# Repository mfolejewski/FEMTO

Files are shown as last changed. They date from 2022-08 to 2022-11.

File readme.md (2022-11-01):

# Femto - RP2040 12x12mm PCB module

## Description

Femto is a ultra compact Raspberry Pi RP2040 module, which has features, as following:
- small footprint 12x12mm,
- all 30 GPIO pins connected,
- stamp form factor,
- 4-layer PCB board,
- onboard: QSPI Flash (USON8 package), 12MHz oscillator, PWR LED,
- fully open source project (OSHW).

Here you can find:
- \Photos: a few pictures of the assembled PCB boards
- \Python: simple script do test Femto module using Femto Tester board (use Thonny IDE)
- \manufacturing_files: all the production files for ordering PCB and assembly at JLCPCB (Gerber files, Pick & Place, BOM, etc.)
- \source_files: source files in Kicad and Altium Designer format

The main goal and reason to create this project was attempt to design as smallest as possible, and fully functional RP2040 module. Please note, that RP2040 MCU nas 7x7mm package, and Femto module has only a bit more, 12x12mm. In comparision, closer competitiors, such as Raspberry Pi Pico or RP2040 Stamp (Solder Party) have appropriately 51x21mm and 25x25mm.

The project consists of 3 parts:
- Module (mainboard)
- frame (solder frame)
- tester (testbench, only for functional verification)

## License

Project published as Open Source Hardware (OSHW) under CERN OHL v1.2 (Open Hardware Licence).



Project has been certified as Open Source Hardware by the Open Source Hardware Association (OSHWA).

UID is: PL000009

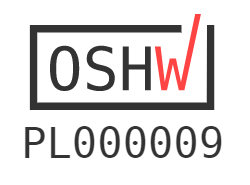
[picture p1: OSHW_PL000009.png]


https://certification.oshwa.org/pl000009.html

## Press release:

[hackster.io](http://hackster.io/news/mirek-folejewski-s-femto-module-is-a-full-feature-raspberry-pi-rp2040-in-the-smallest-footprint-yet-d75727c4adbf.amp)

[cnx-software.com](https://cnx-software.com/2022/08/22/femto-tiny-raspberry-pi-rp2040-module/)

[blingeach.com](https://blingeach.com/mirek-folejewskis-femto-module-is-a-full-function-raspberry-pi-rp2040-within-the-smallest-footprint-but/)

[tecnohub.org](https://tecnohub.org/2022/08/a-full-featured-raspberry-pi-rp2040-in.html?m=1)

[theperfectech.com](https://theperfectech.com/mirek-folejewskis-femto-module-is-a-full-characteristic-raspberry-pi-rp2040-within-the-smallest-footprint-but/)

[hackaday.io](https://hackaday.io/project/186871-femto-module-v1)

## Photos

Raspberry Pico and Femto Module v1:
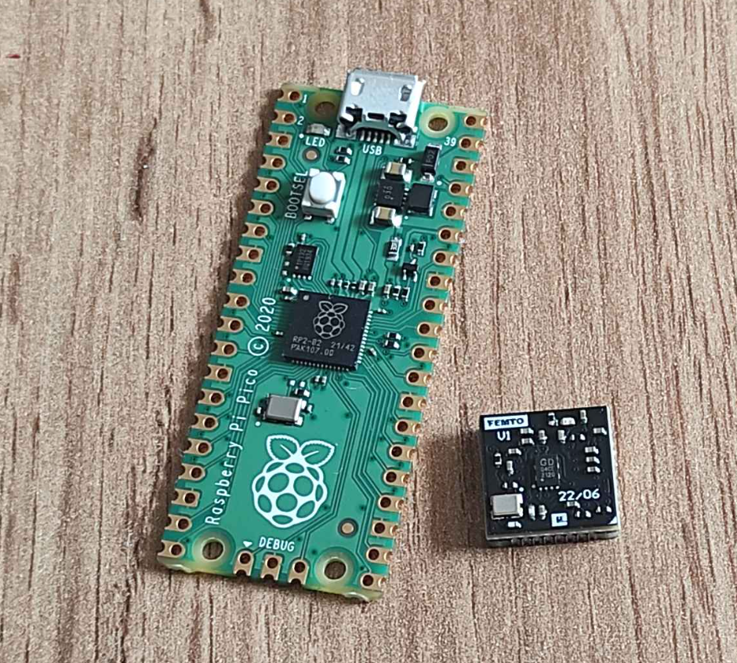
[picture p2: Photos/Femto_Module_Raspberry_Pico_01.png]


Femto Module:
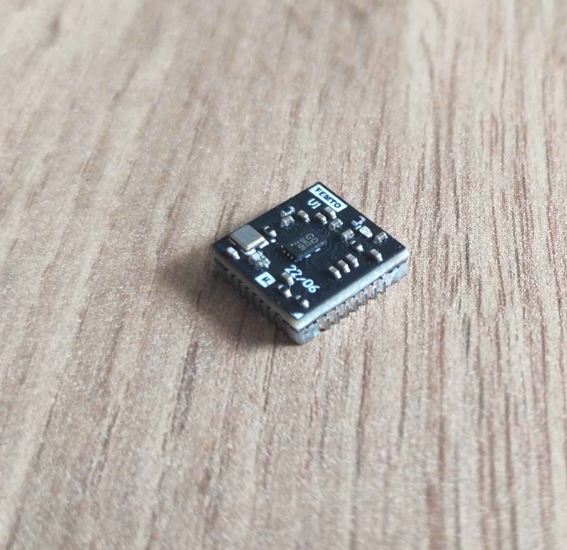
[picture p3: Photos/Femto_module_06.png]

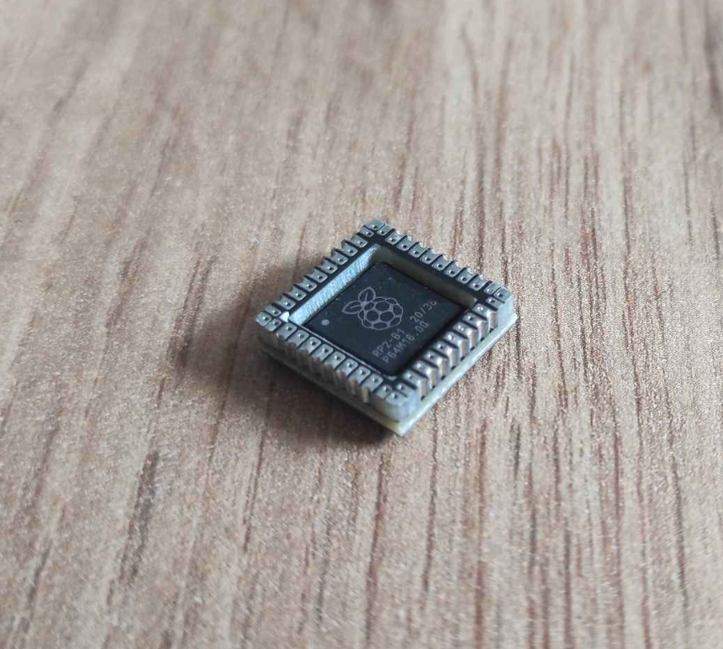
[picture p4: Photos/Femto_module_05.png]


Femto Frame:
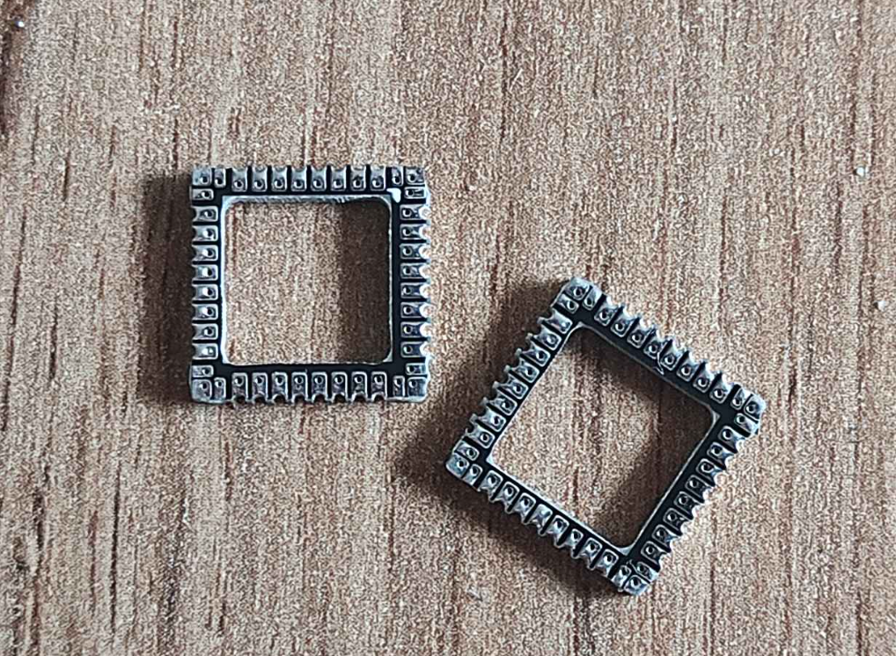
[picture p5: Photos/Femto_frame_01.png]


Femto Tester:
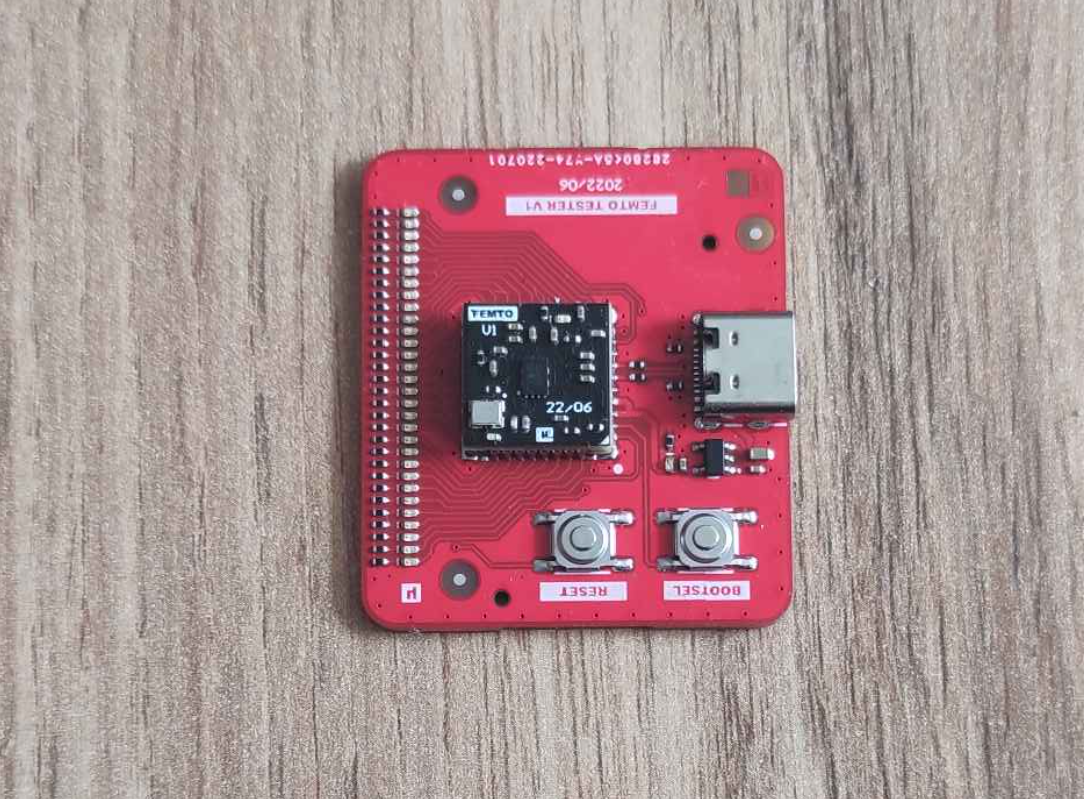
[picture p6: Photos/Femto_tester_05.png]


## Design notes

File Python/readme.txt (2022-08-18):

Python verification script for Femto Tester board

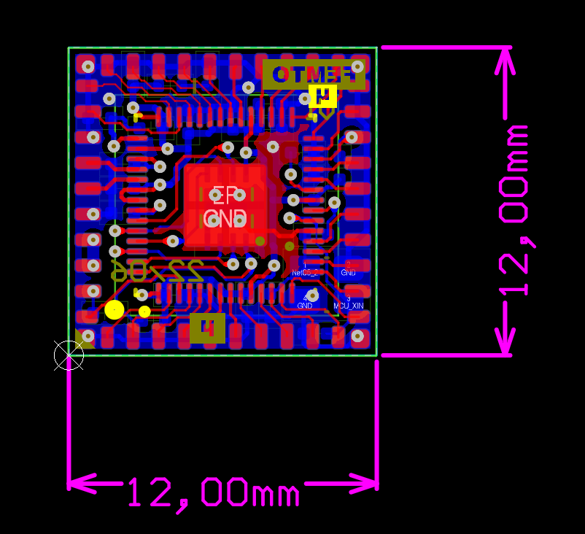
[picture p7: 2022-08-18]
source_files/Altium_Designer/Module/PCB_file_2d_view.png

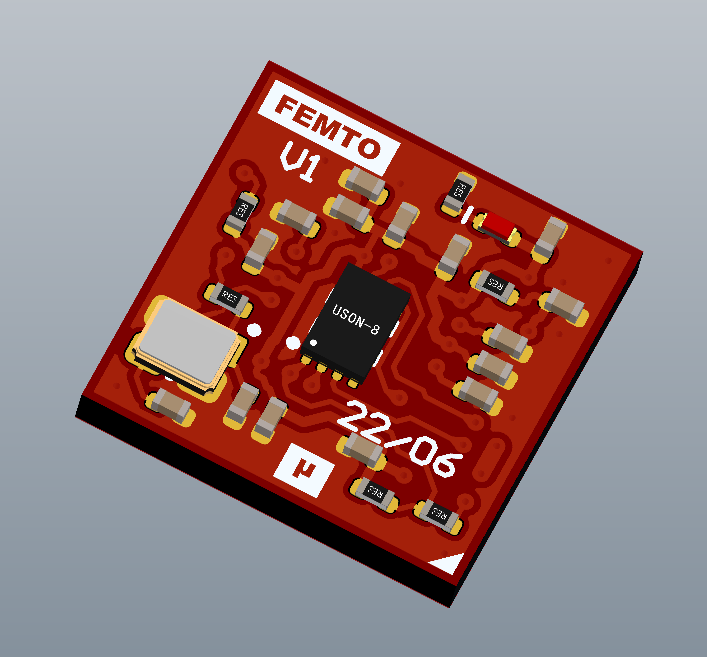
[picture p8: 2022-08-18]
source_files/Altium_Designer/Module/PCB_file_3d_view_bot.png

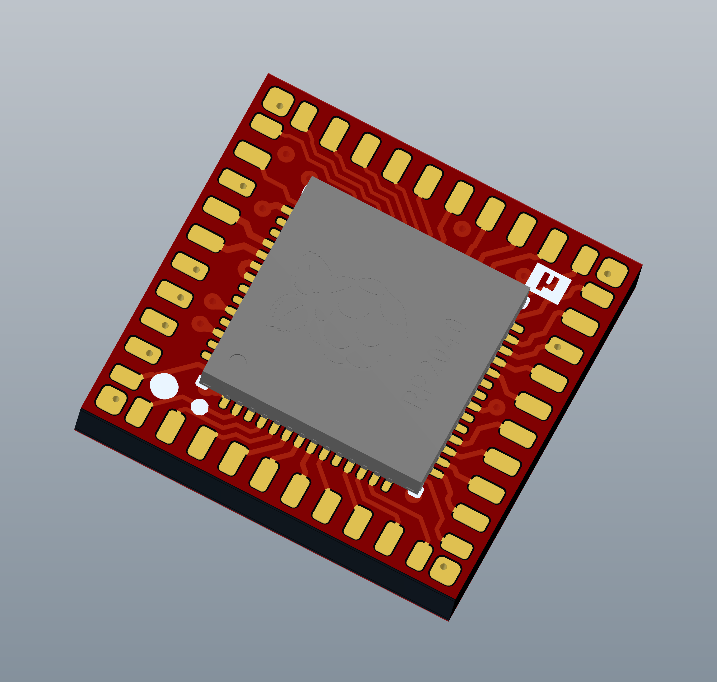
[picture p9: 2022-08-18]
source_files/Altium_Designer/Module/PCB_file_3d_view_top.png

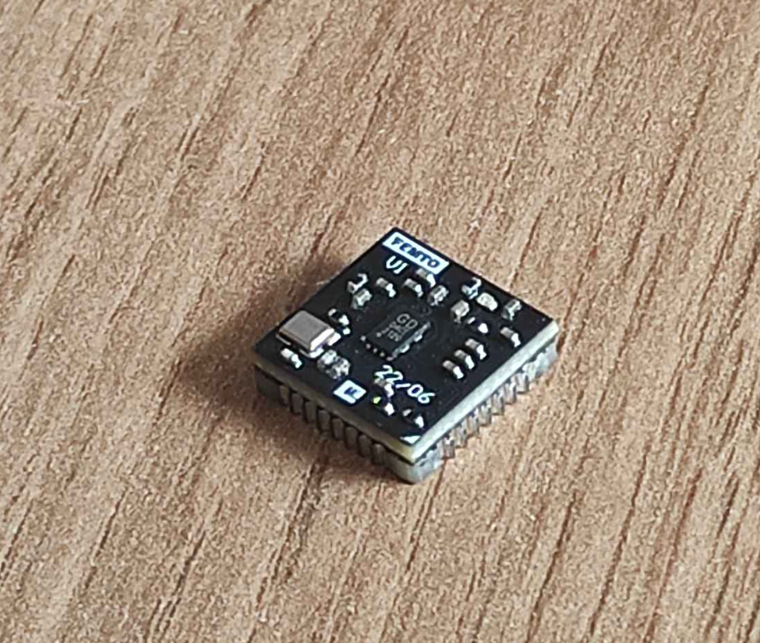
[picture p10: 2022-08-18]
Photos/Femto_module_04.png

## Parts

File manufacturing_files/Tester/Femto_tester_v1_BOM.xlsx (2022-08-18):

Comment | Designator | Package (Case) | Quantity | Supplier 1 | Supplier 2 | Supplier 3 | Supplier Part Number 1 | Supplier Part Number 2 | Supplier Part Number 3
2k | R1, R_GP0, R_GP1, R_GP2, R_GP3, R_GP4, R_GP5, R_GP6, R_GP7, R_GP8, R_GP9, R_GP10, R_GP11, R_GP12, R_GP13, R_GP14, R_GP15, R_GP16, R_GP17, R_GP18, R_GP19, R_GP20, R_GP21, R_GP22, R_GP23, R_GP24, R_GP25, R_GP26, R_GP27, R_GP28, R_GP29 | 0402 (1005) | 31 | LCSC | Farnell | Mouser | C60488 | 1458757 | 603-RC0402FR-072KL
2.2uF | C1, C2 | 0402 (1005) | 2 | LCSC | Farnell | Mouser | C107371 | 3013335 | 187-CL05A225MQ5NNNC
5.1k | R4, R5 | 0402 (1005) | 2 | LCSC | Farnell | Mouser | C105872 | 1458805 | 603-RC0402FR-075K1L
27R | R2, R3 | 0402 (1005) | 2 | LCSC | Farnell | Mouser | C138021 | 9239049 | 603-RC0402FR-0727RL
47uF | C3 | 0603 (1608) | 1 | LCSC | Farnell | Mouser | C140782 | 3582851 | 81-GRM188R60J476ME5J
FEMTO V1 Module | MOD1 |  | 1
NCP114ASN330T1G | U1 |  | 1 | LCSC | Farnell | Mouser | C457666 | 2677151 | 863-NCP114ASN330T1G
Red | LED1, LED_GP0, LED_GP1, LED_GP2, LED_GP3, LED_GP4, LED_GP5, LED_GP6, LED_GP7, LED_GP8, LED_GP9, LED_GP10, LED_GP11, LED_GP12, LED_GP13, LED_GP14, LED_GP15, LED_GP16, LED_GP17, LED_GP18, LED_GP19, LED_GP20, LED_GP21, LED_GP22, LED_GP23, LED_GP24, LED_GP25, LED_GP26, LED_GP27, LED_GP28, LED_GP29 | 0402 (1005) | 31 | LCSC | Farnell | Mouser | C965790 | 2900754 | 710-150040RS73240
TACT Switch | SW1, SW2 | 3780595 | 2 | LCSC | Farnell | Mouser | C221856 | 3023207 | 611-PTS525SM15SMTR2
U262-161N-4BVC11 | J1 | SMD | 1

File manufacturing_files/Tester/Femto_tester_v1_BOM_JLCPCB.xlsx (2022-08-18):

Comment | Designator | Footprint | Supplier Part Number 1
2k | R1, R_GP0, R_GP1, R_GP2, R_GP3, R_GP4, R_GP5, R_GP6, R_GP7, R_GP8, R_GP9, R_GP10, R_GP11, R_GP12, R_GP13, R_GP14, R_GP15, R_GP16, R_GP17, R_GP18, R_GP19, R_GP20, R_GP21, R_GP22, R_GP23, R_GP24, R_GP25, R_GP26, R_GP27, R_GP28, R_GP29 | 0402 (1005) | C60488
2.2uF | C1, C2 | 0402 (1005) | C107371
5.1k | R4, R5 | 0402 (1005) | C105872
27R | R2, R3 | 0402 (1005) | C138021
47uF | C3 | 0603 (1608) | C140782
FEMTO V1 Module | MOD1
NCP114ASN330T1G | U1 |  | C457666
Red | LED1, LED_GP0, LED_GP1, LED_GP2, LED_GP3, LED_GP4, LED_GP5, LED_GP6, LED_GP7, LED_GP8, LED_GP9, LED_GP10, LED_GP11, LED_GP12, LED_GP13, LED_GP14, LED_GP15, LED_GP16, LED_GP17, LED_GP18, LED_GP19, LED_GP20, LED_GP21, LED_GP22, LED_GP23, LED_GP24, LED_GP25, LED_GP26, LED_GP27, LED_GP28, LED_GP29 | 0402 (1005) | C965790
TACT Switch | SW1, SW2 | 3780595 | C221856
U262-161N-4BVC11 | J1 | SMD

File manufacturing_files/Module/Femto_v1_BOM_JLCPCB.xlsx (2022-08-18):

Comment | Designator | Footprint | Supplier Part Number 1
1k | R5, R6 | 0402 (1005) | C106235
2k | R33 | 0402 (1005) | C60488
2.2uF | C4, C15, C16, C17 | 0402 (1005) | C107371
10k | R3, R4 | 0402 (1005) | C60490
12.000MHz | X1 | SMD 2520 | C2149205
15pF | C5, C6 | 0402 (1005) | C106997
100nF | C3, C7, C8, C9, C10, C11, C12, C13, C14 | 0402 (1005) | C155422
100R | R7 | 0402 (1005) | C106232
Red | LED26 | 0402 (1005) | C965790
RP2040 | U1 | QFN-56 | C2040
W25Q16JV | U2 |  | C2843335

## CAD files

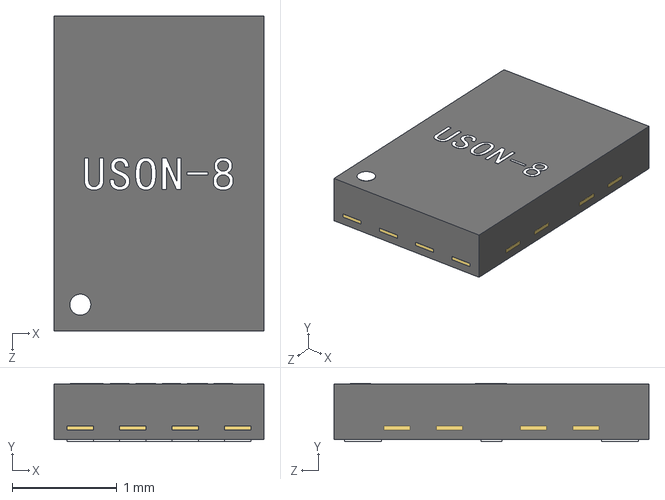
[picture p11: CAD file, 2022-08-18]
source_files/Kicad/Module/ALTIUM_EMBEDDED_MODELS/USON-8_3x2x0_55mm.step
2.00 x 0.553 x 3.00 mm

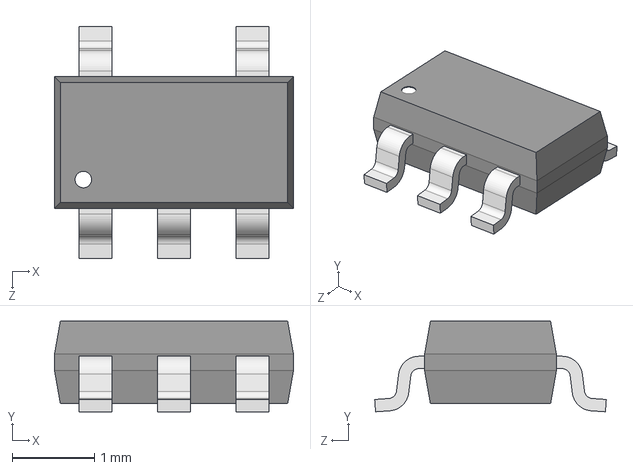
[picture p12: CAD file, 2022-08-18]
source_files/Kicad/Tester/ALTIUM_EMBEDDED_MODELS/TSOT-5.step
2.90 x 1.10 x 2.81 mm

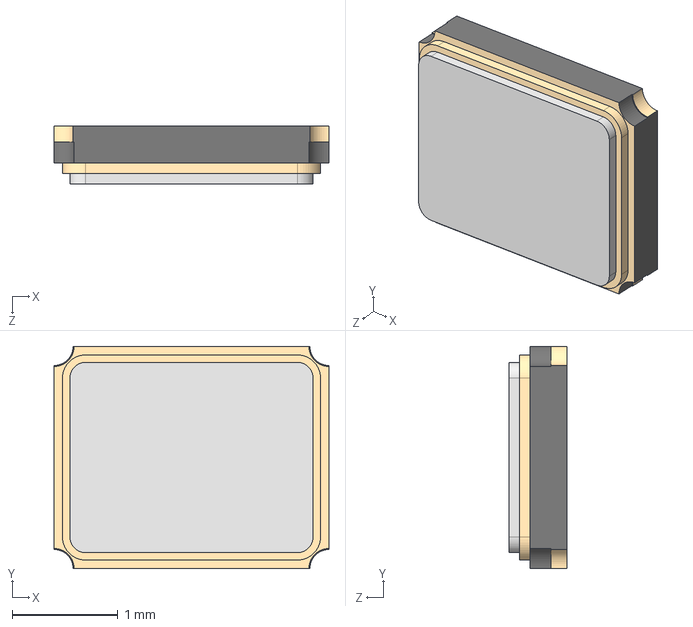
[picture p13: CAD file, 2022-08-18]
source_files/Kicad/Module/ALTIUM_EMBEDDED_MODELS/Crystal_2520_2.5x2.0x0.5.step
2.60 x 2.10 x 0.55 mm

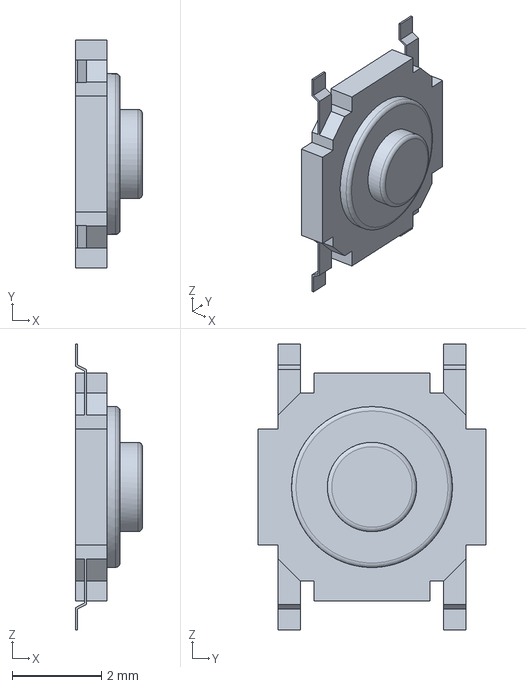
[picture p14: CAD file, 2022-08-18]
source_files/Kicad/Tester/ALTIUM_EMBEDDED_MODELS/CK_PTS525SM15SMTR2LFS.stp
1.50 x 5.10 x 6.40 mm

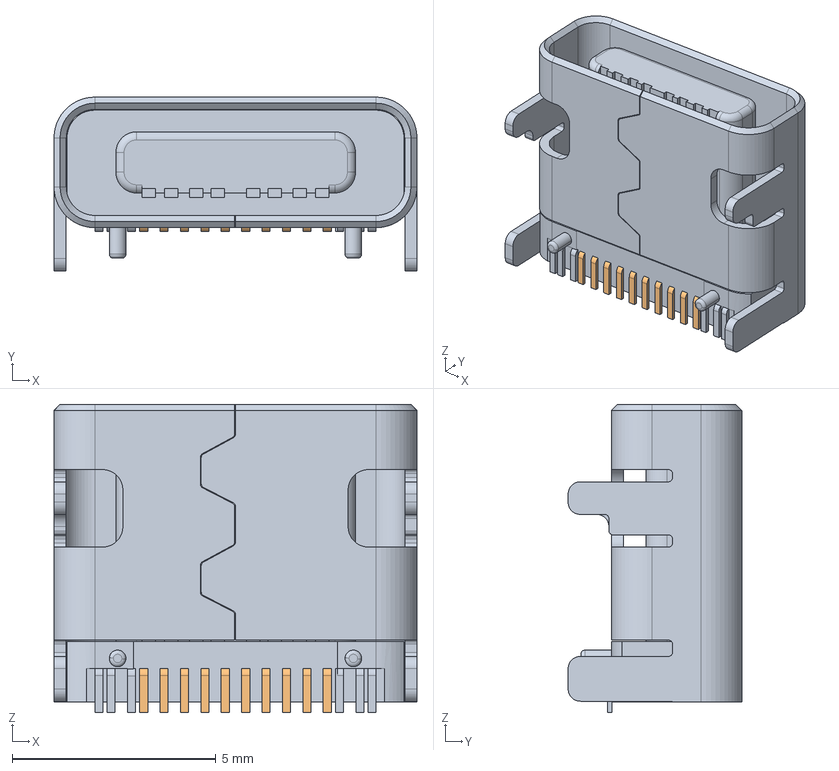
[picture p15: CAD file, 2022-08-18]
source_files/Kicad/Tester/ALTIUM_EMBEDDED_MODELS/XKB-Connectivity_U262-161N-4BVC11.stp
8.90 x 4.26 x 7.56 mm

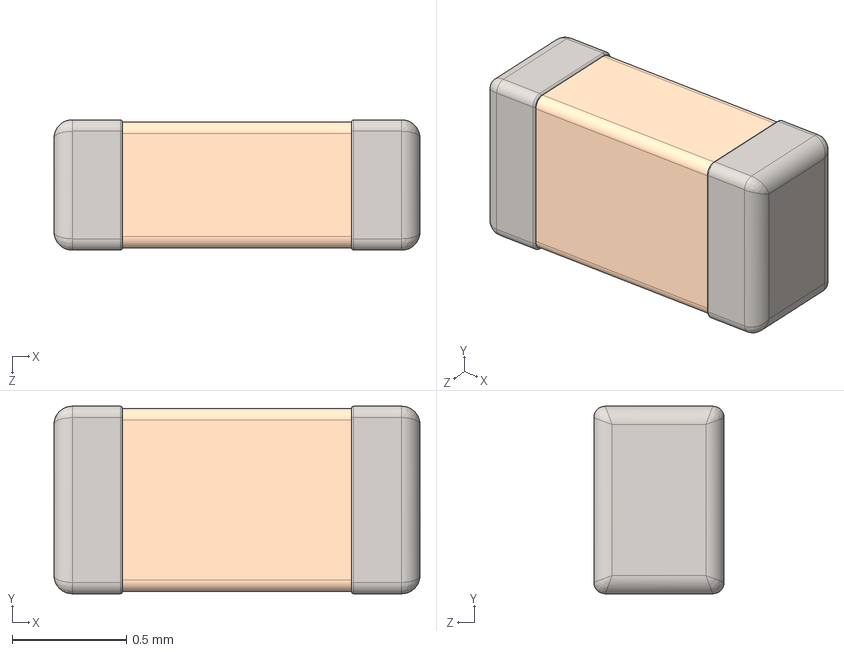
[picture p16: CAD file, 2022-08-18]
source_files/Kicad/Tester/ALTIUM_EMBEDDED_MODELS/CAPC1608X_0603.step
1.60 x 0.82 x 0.57 mm

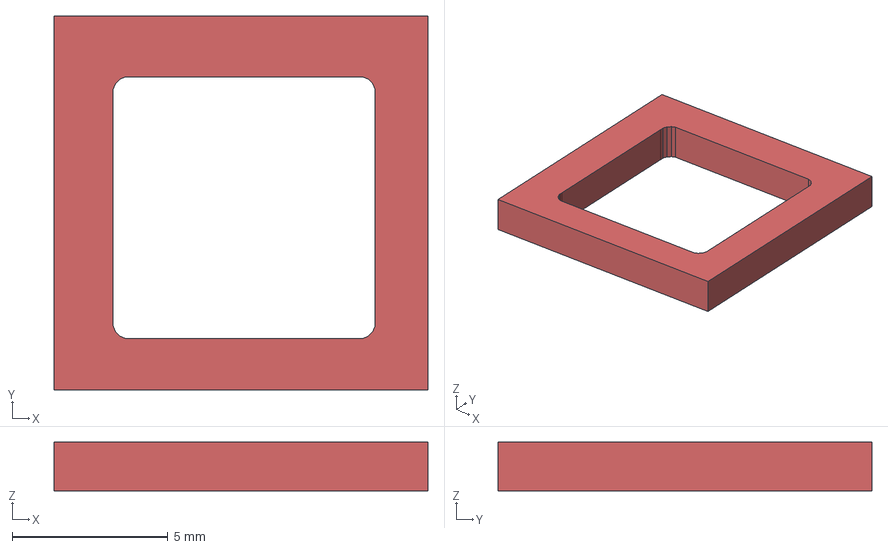
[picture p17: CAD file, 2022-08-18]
source_files/Kicad/Tester/ALTIUM_EMBEDDED_MODELS/Femto_frame.step
12.0 x 12.0 x 1.56 mm

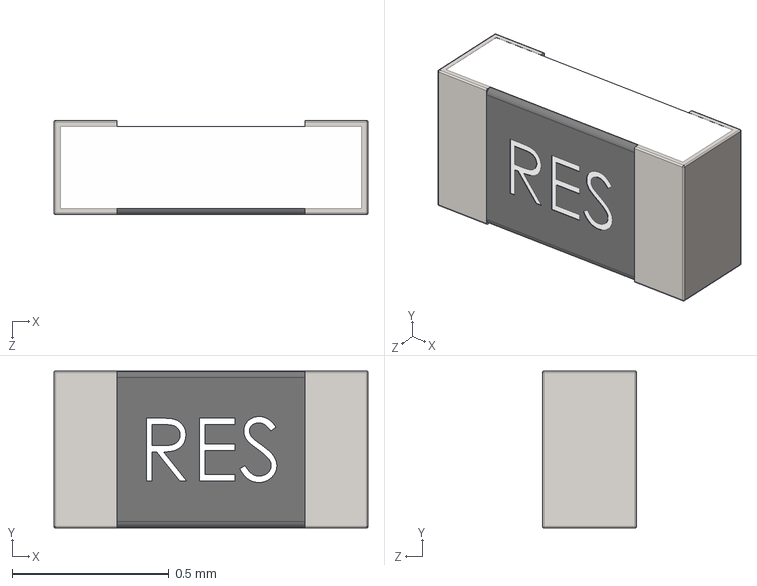
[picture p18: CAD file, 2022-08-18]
source_files/Kicad/Tester/ALTIUM_EMBEDDED_MODELS/RESC1005X_0402.step
1.00 x 0.5 x 0.3 mm

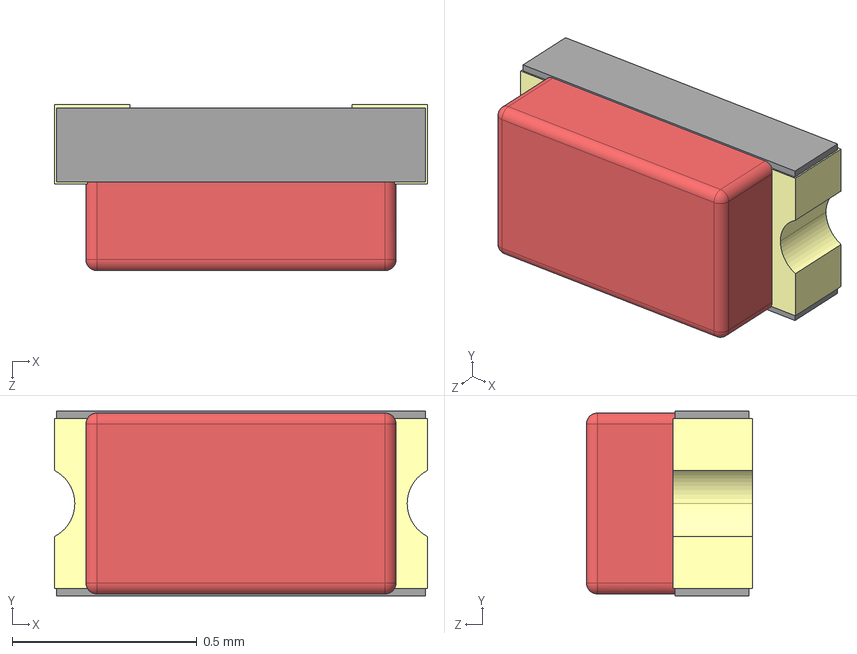
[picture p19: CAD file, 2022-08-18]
source_files/Kicad/Tester/ALTIUM_EMBEDDED_MODELS/LED_0402.step
1.01 x 0.5 x 0.45 mm

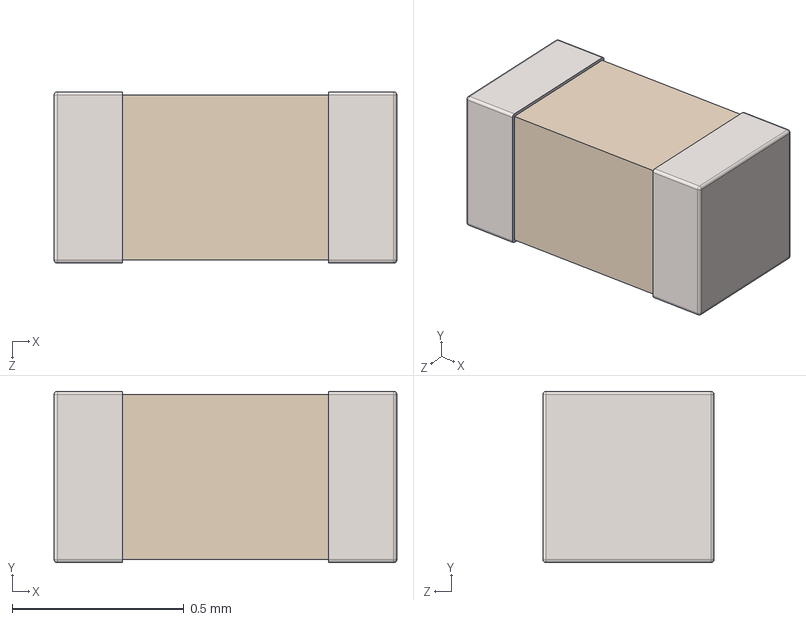
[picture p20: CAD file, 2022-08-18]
source_files/Kicad/Tester/ALTIUM_EMBEDDED_MODELS/CAP0402.step
1.00 x 0.5 x 0.5 mm

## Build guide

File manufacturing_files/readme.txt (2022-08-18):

FEMTO - RP2040 12x12mm PCB Module

Manufacturing files:
- GERBER
- Assembly
- Pick & Place
- BOM

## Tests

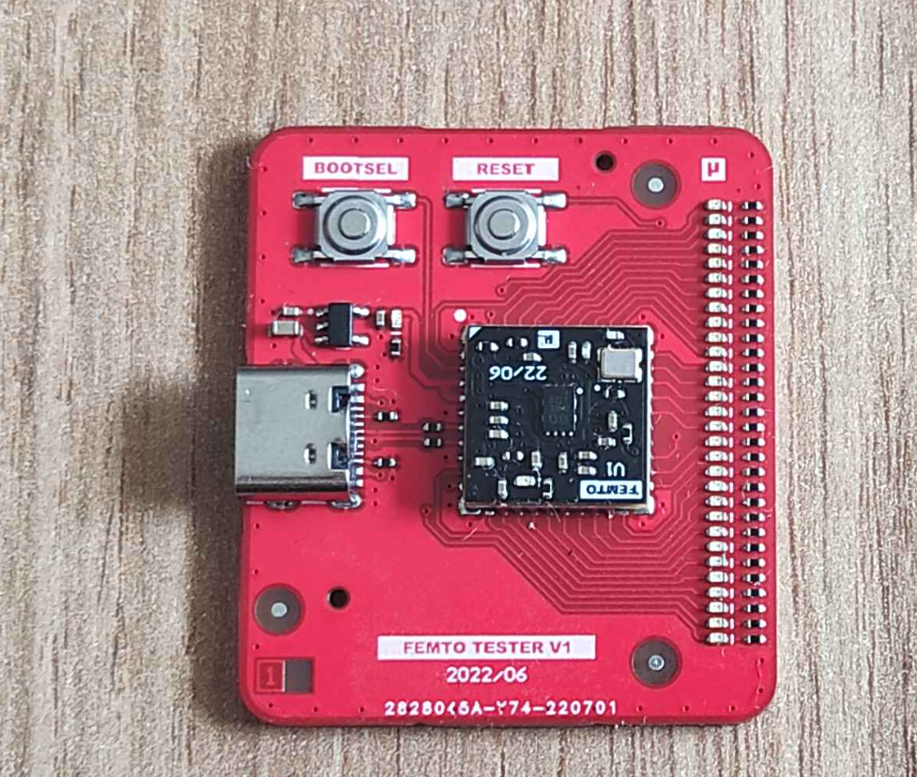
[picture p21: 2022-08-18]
Photos/Femto_tester_01.png

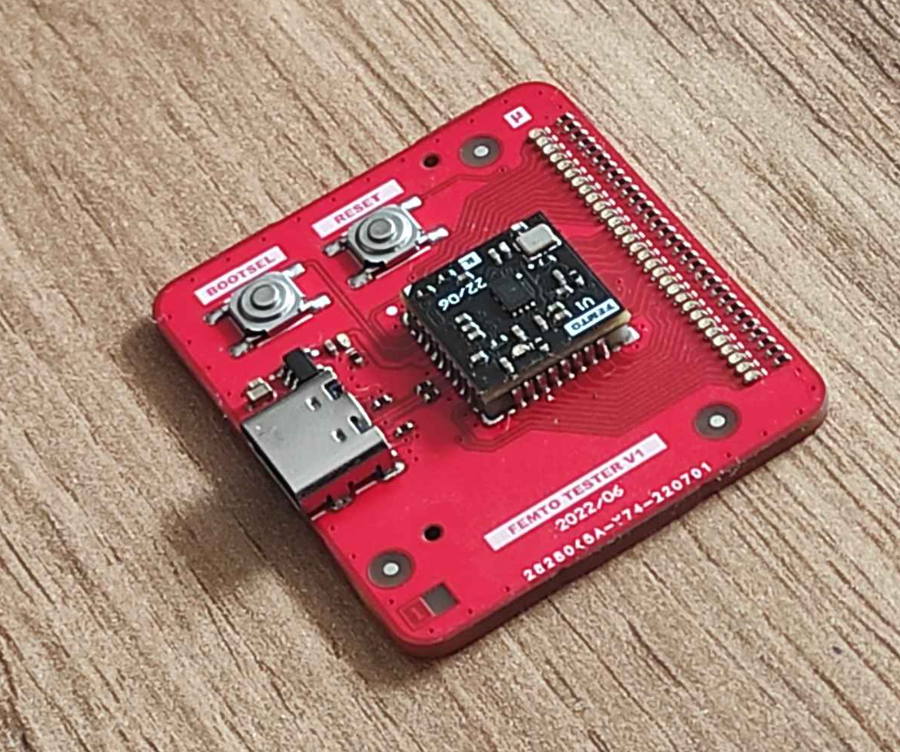
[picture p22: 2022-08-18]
Photos/Femto_tester_02.png

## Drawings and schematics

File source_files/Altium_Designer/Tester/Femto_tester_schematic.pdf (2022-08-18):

A | FEMTO V1 MODULE | A

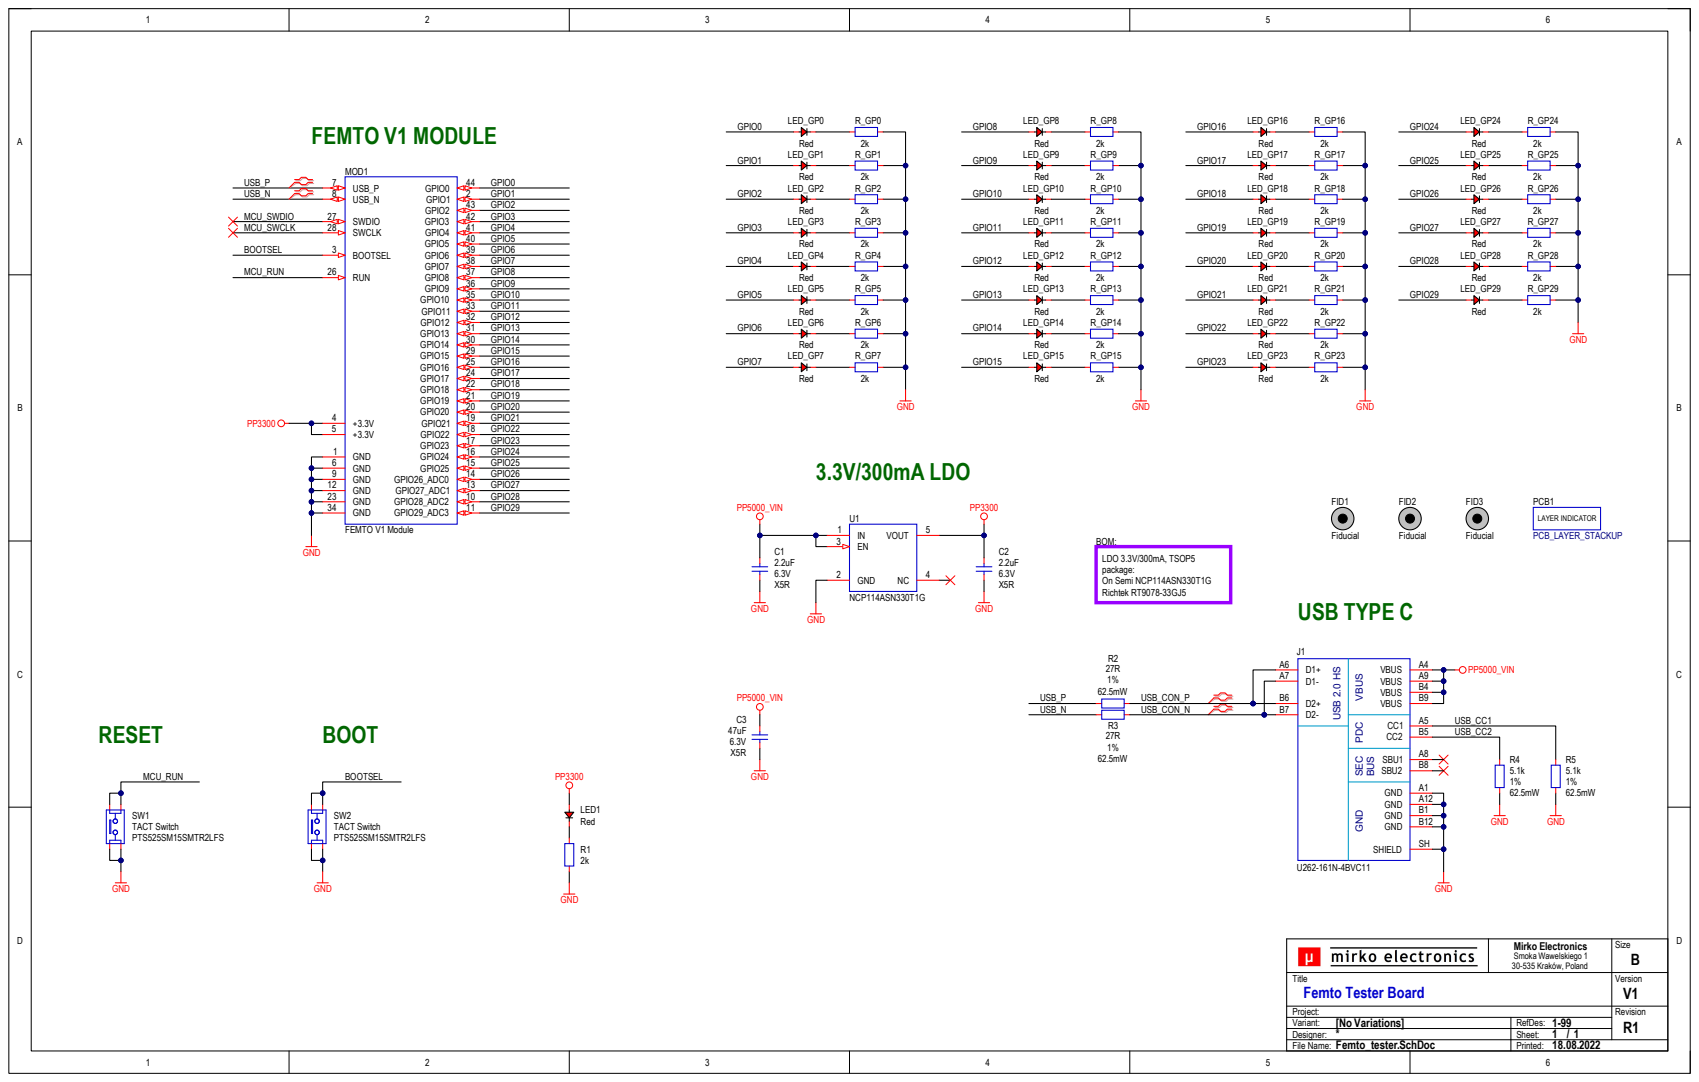
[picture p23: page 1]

Mirko Electronics Smoka Wawelskiego 1 30-535 Kraków, Poland | Size B

Title Femto Tester Board | | Version V1

Project: | | Revision R1
Variant: [No Variations] | RefDes: 1-99
Designer: * | Sheet: 1 1 /
File Name: | Printed: Femto_tester.SchDoc 18.08.2022

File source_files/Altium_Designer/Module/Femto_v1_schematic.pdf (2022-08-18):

# RP2040 MCU

# QSPI FLASH

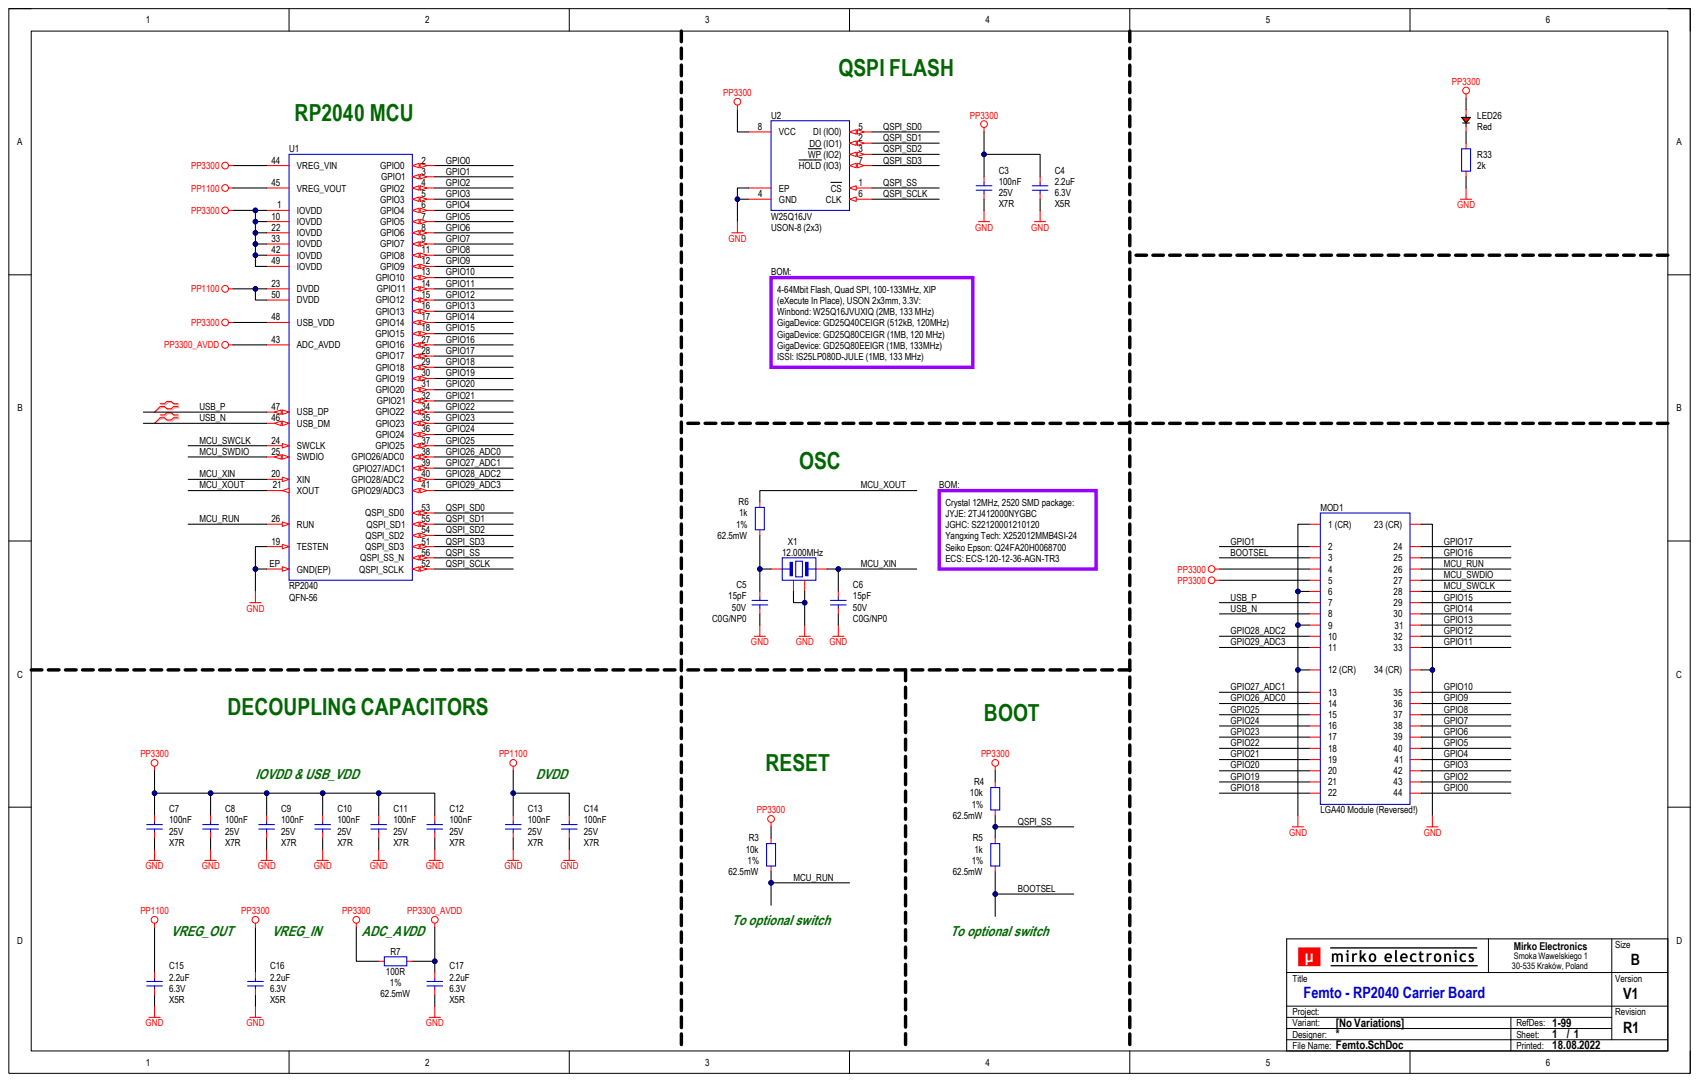
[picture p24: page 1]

BOM:
4-64Mbit Flash, Quad SPI, 100-133MHz, XIP
(eXecute In Place), USON 2x3mm, 3.3V:
Winbond: W25Q16JVUXIQ (2MB, 133 MHz)
GigaDevice: GD25Q40CEIGR (512kB, 120MHz)
GigaDevice: GD25Q80CEIGR (1MB, 120 MHz)
GigaDevice: GD25Q80EEIGR (1MB, 133MHz)
ISSI: IS25LP080D-JULE (1MB, 133 MHz)

Mirko Electronics Smoka Wawelskiego 1 30-535 Kraków, Poland | Size B

Title Femto - RP2040 Carrier Board | | Version V1

Project: | | Revision R1
Variant: [No Variations] | RefDes: 1-99
Designer: * | Sheet: 1 1 /
File Name: | Printed: Femto.SchDoc 18.08.2022

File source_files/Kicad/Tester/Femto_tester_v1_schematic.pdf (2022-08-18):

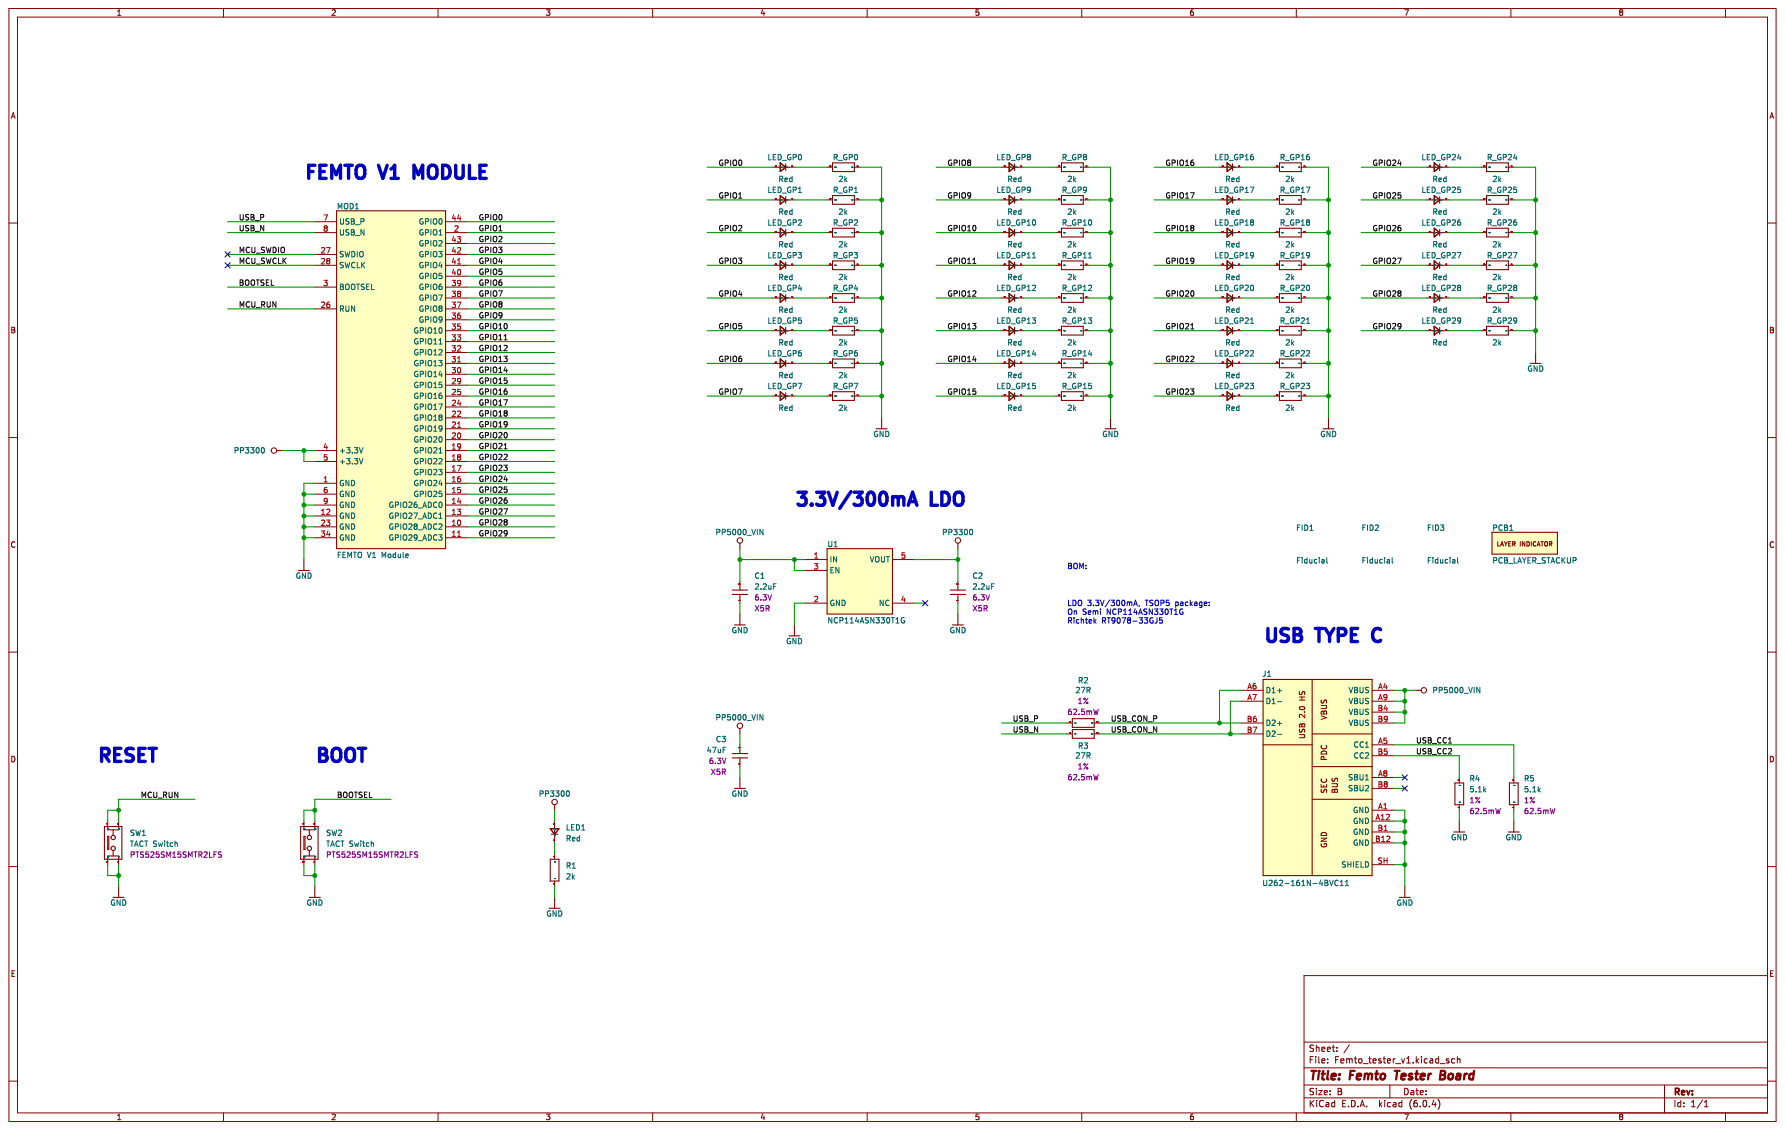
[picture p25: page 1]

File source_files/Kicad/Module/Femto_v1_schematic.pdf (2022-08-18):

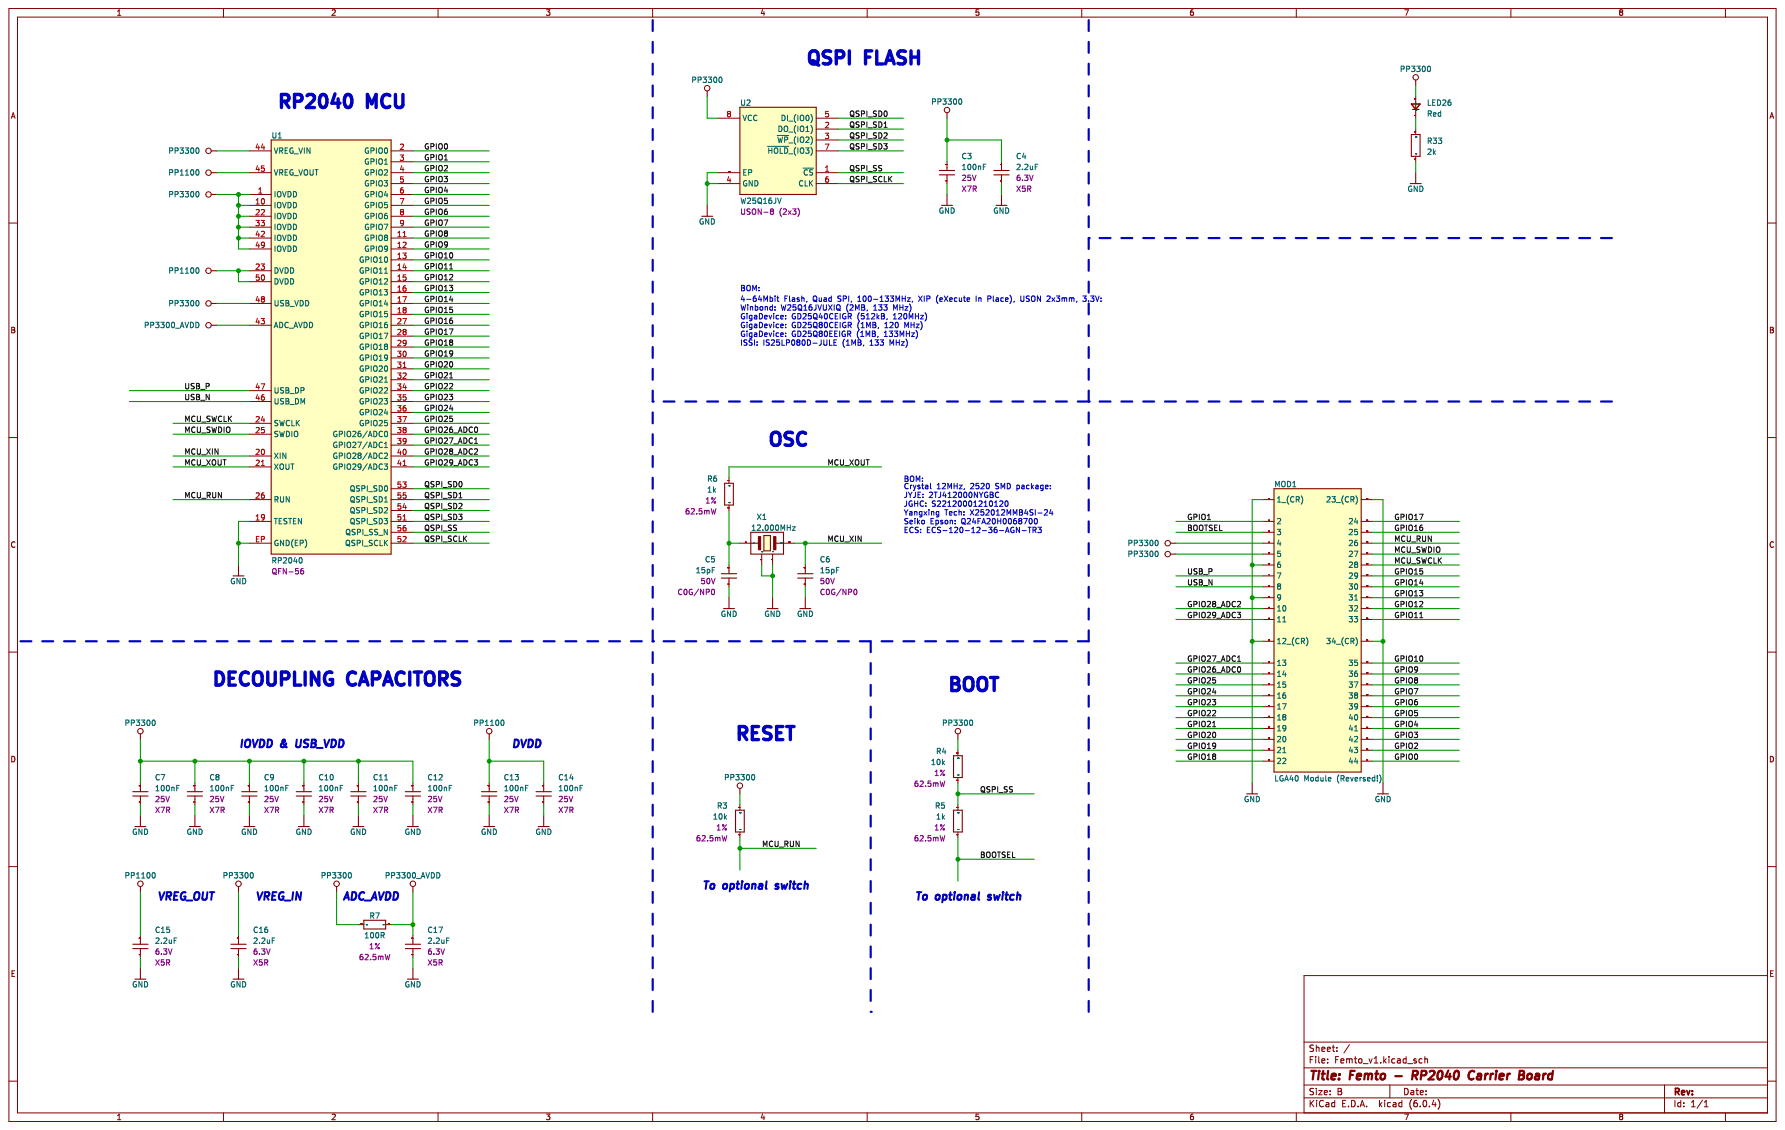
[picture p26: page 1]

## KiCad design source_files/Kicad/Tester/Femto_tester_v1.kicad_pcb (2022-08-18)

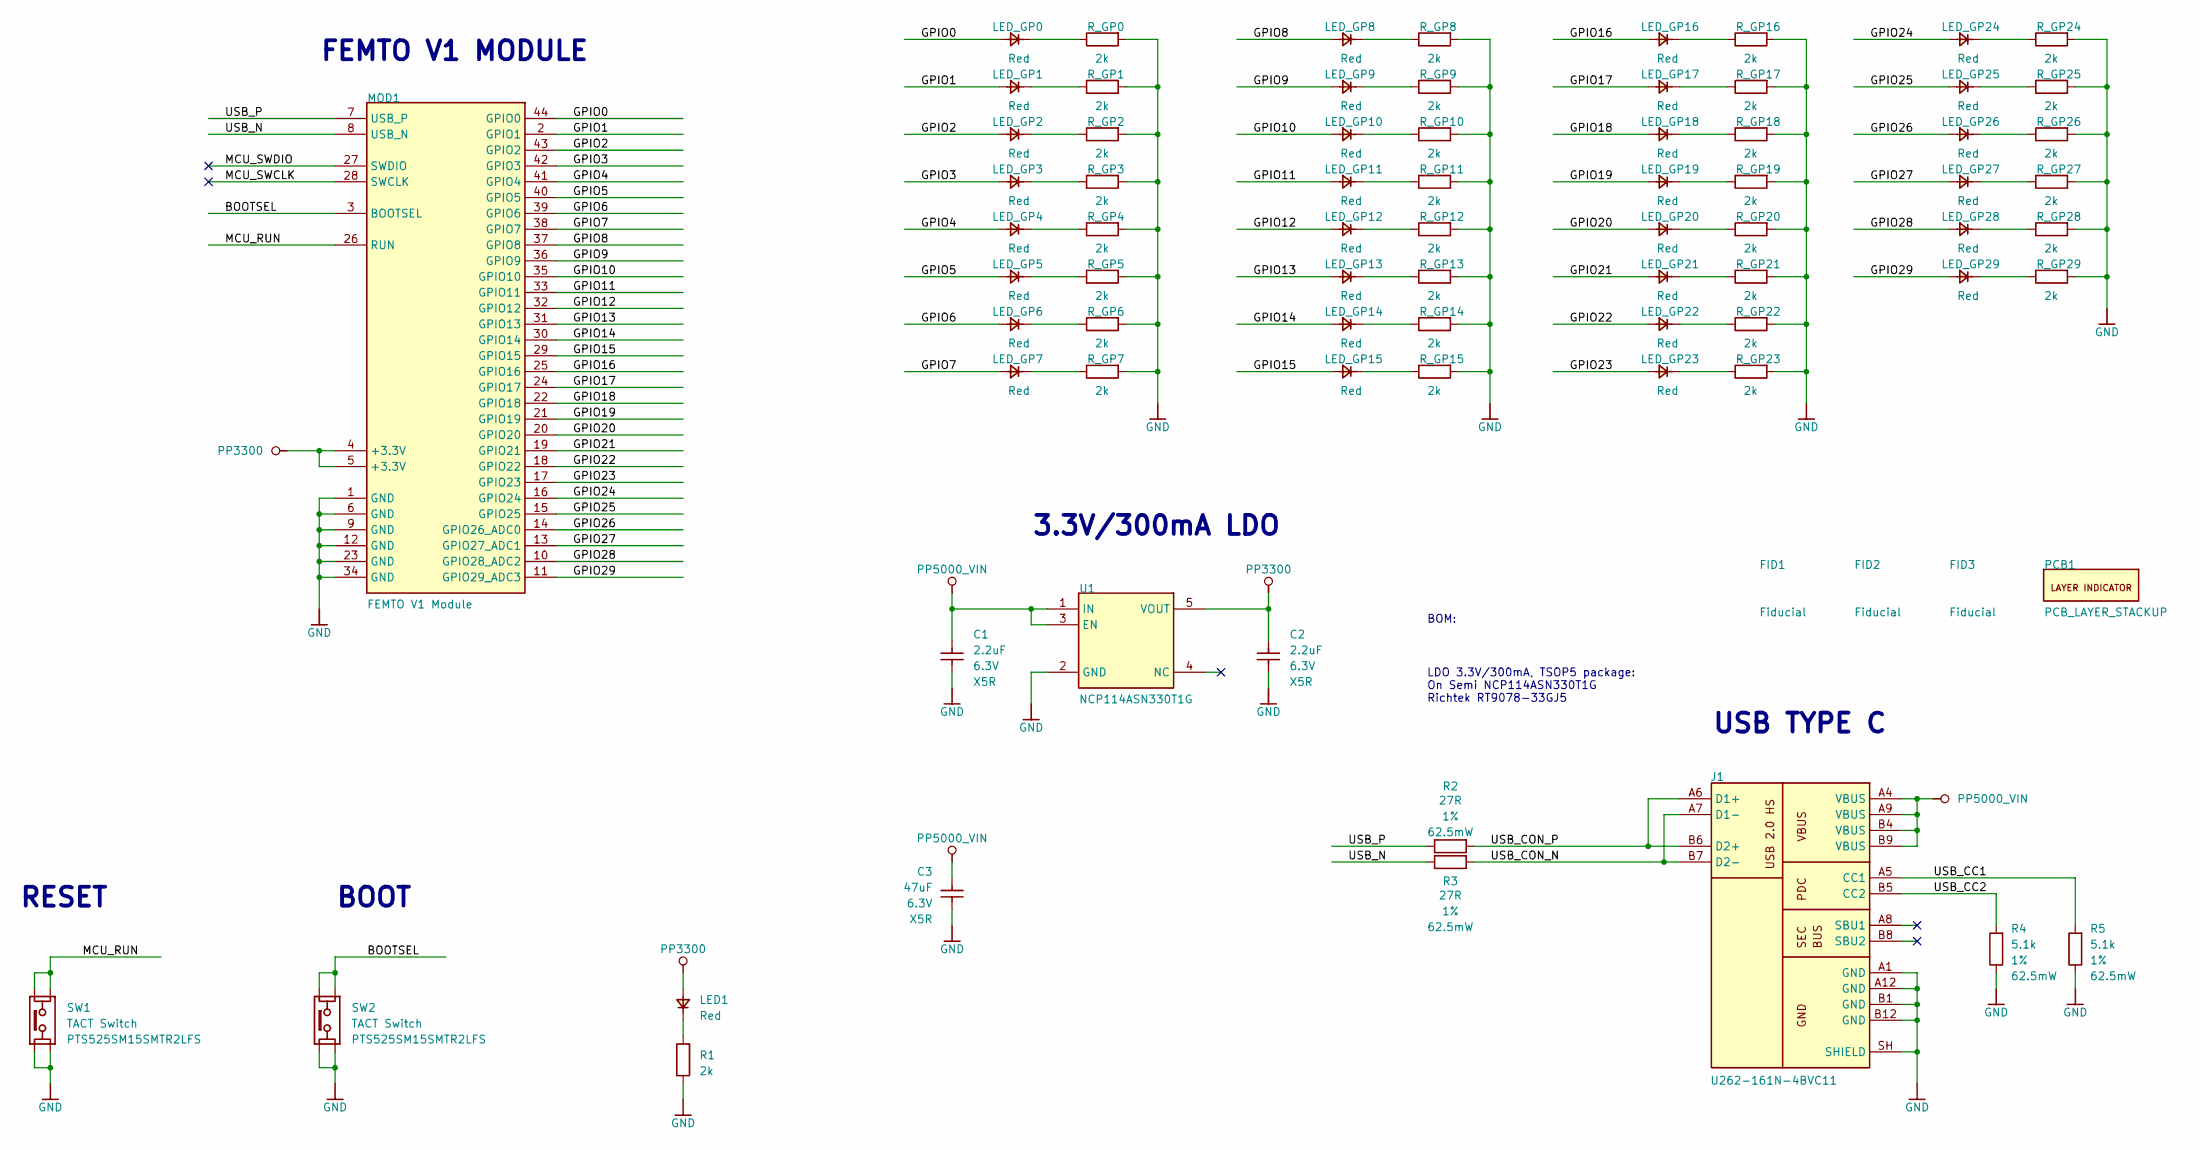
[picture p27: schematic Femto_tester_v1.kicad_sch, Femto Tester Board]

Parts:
C1, C2: 2.2uF; CAP_0402_R; VOLTAGE RATING 6.3V; TOLERANCE TBD; MPN CL05A225MQ5NNNC
C3: 47uF; CAP_0603_R; VOLTAGE RATING 6.3V; TOLERANCE TBD; MPN GENERIC
FID1, FID2, FID3: Fiducial; PCB_FID_RND_100x300
J1: U262-161N-4BVC11; CON_XKB_U262-161N-4BVC11; MPN U262-161N-4BVC11
LED1: Red; LED_0402_R
LED_GP0, LED_GP1, LED_GP2, LED_GP3, LED_GP4, LED_GP5, LED_GP6, LED_GP7, LED_GP8, LED_GP9, LED_GP10, LED_GP11, LED_GP12, LED_GP13, LED_GP14, LED_GP15, LED_GP16, LED_GP17, LED_GP18, LED_GP19, LED_GP20, LED_GP21, LED_GP22, LED_GP23, LED_GP24, LED_GP25, LED_GP26, LED_GP27, LED_GP28, LED_GP29: Red; LED_0402_R
MOD1: FEMTO V1 Module; _Biblioteki_MirFol_nowe_Pineberry_Lib.PcbLib_MOD_FEMTO_V1_1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
PCB1: PCB_LAYER_STACKUP; PCB_STACKUP-2L_A1
R1: 2k; RES_0402_R; TOLERANCE 1%; POWER RATING 62.5mW; MPN RC0402FR-072KP
R2, R3: 27R; RES_0402_R; TOLERANCE 1%; POWER RATING 62.5mW; MPN RC0402FR-0727RL
R4, R5: 5.1k; RES_0402_R; TOLERANCE 1%; POWER RATING 62.5mW; MPN RC0402FR-075K1L
R_GP0, R_GP1, R_GP2, R_GP3, R_GP4, R_GP5, R_GP6, R_GP7, R_GP8, R_GP9, R_GP10, R_GP11, R_GP12, R_GP13, R_GP14, R_GP15, R_GP16, R_GP17, R_GP18, R_GP19, R_GP20, R_GP21, R_GP22, R_GP23, R_GP24, R_GP25, R_GP26, R_GP27, R_GP28, R_GP29: 2k; RES_0402_R; TOLERANCE 1%; POWER RATING 62.5mW; MPN RC0402FR-072KP
SW1, SW2: TACT Switch; SWI_CKS_PTS525; MPN PTS525SM15SMTR2LFS
U1: NCP114ASN330T1G; _Biblioteki_MirFol_nowe_SH_lib.PcbLib_ICC_TSOT-5_290X160H11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; MPN NCP114ASN330T1G

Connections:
/BOOTSEL: MOD1.3 (BOOTSEL), SW2.1, SW2.2
/GPIO0: LED_GP0.2, MOD1.44 (GPIO0)
/GPIO1: LED_GP1.2, MOD1.2 (GPIO1)
/GPIO2: LED_GP2.2, MOD1.43 (GPIO2)
/GPIO3: LED_GP3.2, MOD1.42 (GPIO3)
/GPIO4: LED_GP4.2, MOD1.41 (GPIO4)
/GPIO5: LED_GP5.2, MOD1.40 (GPIO5)
/GPIO6: LED_GP6.2, MOD1.39 (GPIO6)
/GPIO7: LED_GP7.2, MOD1.38 (GPIO7)
/GPIO8: LED_GP8.2, MOD1.37 (GPIO8)
/GPIO9: LED_GP9.2, MOD1.36 (GPIO9)
/GPIO10: LED_GP10.2, MOD1.35 (GPIO10)
/GPIO11: LED_GP11.2, MOD1.33 (GPIO11)
/GPIO12: LED_GP12.2, MOD1.32 (GPIO12)
/GPIO13: LED_GP13.2, MOD1.31 (GPIO13)
/GPIO14: LED_GP14.2, MOD1.30 (GPIO14)
/GPIO15: LED_GP15.2, MOD1.29 (GPIO15)
/GPIO16: LED_GP16.2, MOD1.25 (GPIO16)
/GPIO17: LED_GP17.2, MOD1.24 (GPIO17)
/GPIO18: LED_GP18.2, MOD1.22 (GPIO18)
/GPIO19: LED_GP19.2, MOD1.21 (GPIO19)
/GPIO20: LED_GP20.2, MOD1.20 (GPIO20)
/GPIO21: LED_GP21.2, MOD1.19 (GPIO21)
/GPIO22: LED_GP22.2, MOD1.18 (GPIO22)
/GPIO23: LED_GP23.2, MOD1.17 (GPIO23)
/GPIO24: LED_GP24.2, MOD1.16 (GPIO24)
/GPIO25: LED_GP25.2, MOD1.15 (GPIO25)
/GPIO26: LED_GP26.2, MOD1.14 (GPIO26_ADC0)
/GPIO27: LED_GP27.2, MOD1.13 (GPIO27_ADC1)
/GPIO28: LED_GP28.2, MOD1.10 (GPIO28_ADC2)
/GPIO29: LED_GP29.2, MOD1.11 (GPIO29_ADC3)
/MCU_RUN: MOD1.26 (RUN), SW1.1, SW1.2
/MCU_SWCLK: MOD1.28 (SWCLK)
/MCU_SWDIO: MOD1.27 (SWDIO)
/USB_CC1: J1.A5 (CC1), R5.2
/USB_CC2: J1.B5 (CC2), R4.2
/USB_CON_N: J1.A7 (D1-), J1.B7 (D2-), R3.2
/USB_CON_P: J1.A6 (D1+), J1.B6 (D2+), R2.2
/USB_N: MOD1.8 (USB_N), R3.1
/USB_P: MOD1.7 (USB_P), R2.1
GND: C1.1, C2.1, C3.1, J1.A1 (GND), J1.A12 (GND), J1.B1 (GND), J1.B12 (GND), J1.SH (SHIELD), MOD1.1 (GND), MOD1.6 (GND), MOD1.9 (GND), MOD1.12 (GND), MOD1.23 (GND), MOD1.34 (GND), R1.1, R4.1, R5.1, R_GP0.1, R_GP1.1, R_GP2.1, R_GP3.1, R_GP4.1, R_GP5.1, R_GP6.1, R_GP7.1, R_GP8.1, R_GP9.1, R_GP10.1, R_GP11.1, R_GP12.1, R_GP13.1, R_GP14.1, R_GP15.1, R_GP16.1, R_GP17.1, R_GP18.1, R_GP19.1, R_GP20.1, R_GP21.1, R_GP22.1, R_GP23.1, R_GP24.1, R_GP25.1, R_GP26.1, R_GP27.1, R_GP28.1, R_GP29.1, SW1.3, SW1.4, SW2.3, SW2.4, U1.2 (GND)
unnamed: LED1.1, R1.2
unnamed: LED_GP0.1, R_GP0.2
unnamed: LED_GP1.1, R_GP1.2
unnamed: LED_GP2.1, R_GP2.2
unnamed: LED_GP3.1, R_GP3.2
unnamed: LED_GP4.1, R_GP4.2
unnamed: LED_GP5.1, R_GP5.2
unnamed: LED_GP6.1, R_GP6.2
unnamed: LED_GP7.1, R_GP7.2
unnamed: LED_GP8.1, R_GP8.2
unnamed: LED_GP9.1, R_GP9.2
unnamed: LED_GP10.1, R_GP10.2
unnamed: LED_GP11.1, R_GP11.2
unnamed: LED_GP12.1, R_GP12.2
unnamed: LED_GP13.1, R_GP13.2
unnamed: LED_GP14.1, R_GP14.2
unnamed: LED_GP15.1, R_GP15.2
unnamed: LED_GP16.1, R_GP16.2
unnamed: LED_GP17.1, R_GP17.2
unnamed: LED_GP18.1, R_GP18.2
unnamed: LED_GP19.1, R_GP19.2
unnamed: LED_GP20.1, R_GP20.2
unnamed: LED_GP21.1, R_GP21.2
unnamed: LED_GP22.1, R_GP22.2
unnamed: LED_GP23.1, R_GP23.2
unnamed: LED_GP24.1, R_GP24.2
unnamed: LED_GP25.1, R_GP25.2
unnamed: LED_GP26.1, R_GP26.2
unnamed: LED_GP27.1, R_GP27.2
unnamed: LED_GP28.1, R_GP28.2
unnamed: LED_GP29.1, R_GP29.2
PP3300: C2.2, LED1.2, MOD1.4 (+3.3V), MOD1.5 (+3.3V), U1.5 (VOUT)
PP5000_VIN: C1.2, C3.2, J1.A4 (VBUS), J1.A9 (VBUS), J1.B4 (VBUS), J1.B9 (VBUS), U1.1 (IN), U1.3 (EN)

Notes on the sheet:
BOM:
USB TYPE C
BOOT
3.3V/300mA LDO
FEMTO V1 MODULE
RESET
LDO 3.3V/300mA, TSOP5 package: On Semi NCP114ASN330T1G Richtek RT9078-33GJ5

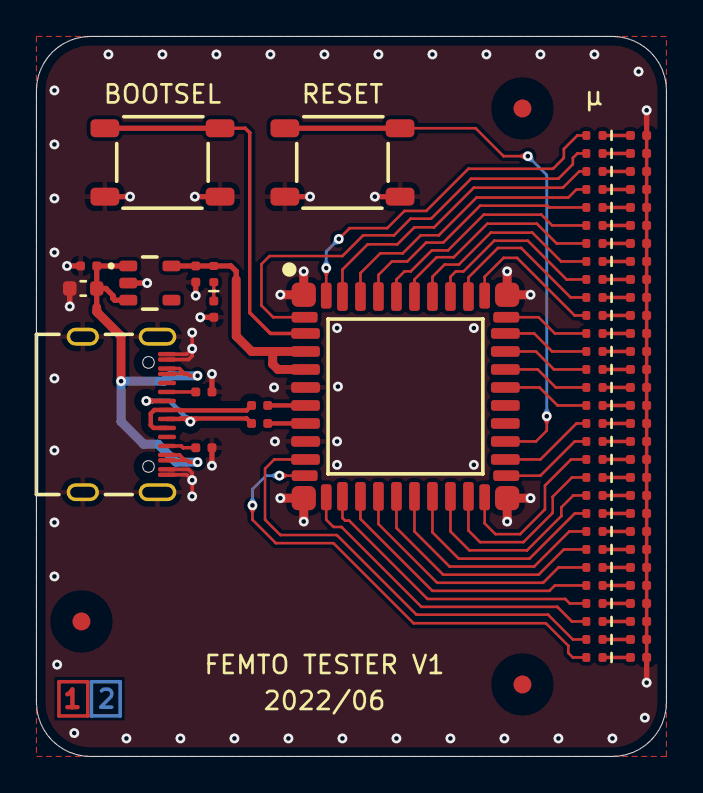
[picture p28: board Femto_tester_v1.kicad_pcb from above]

Board: 2 copper layers, 35.0 x 40.0 mm, 78 parts (0 on the bottom side), 72 nets.

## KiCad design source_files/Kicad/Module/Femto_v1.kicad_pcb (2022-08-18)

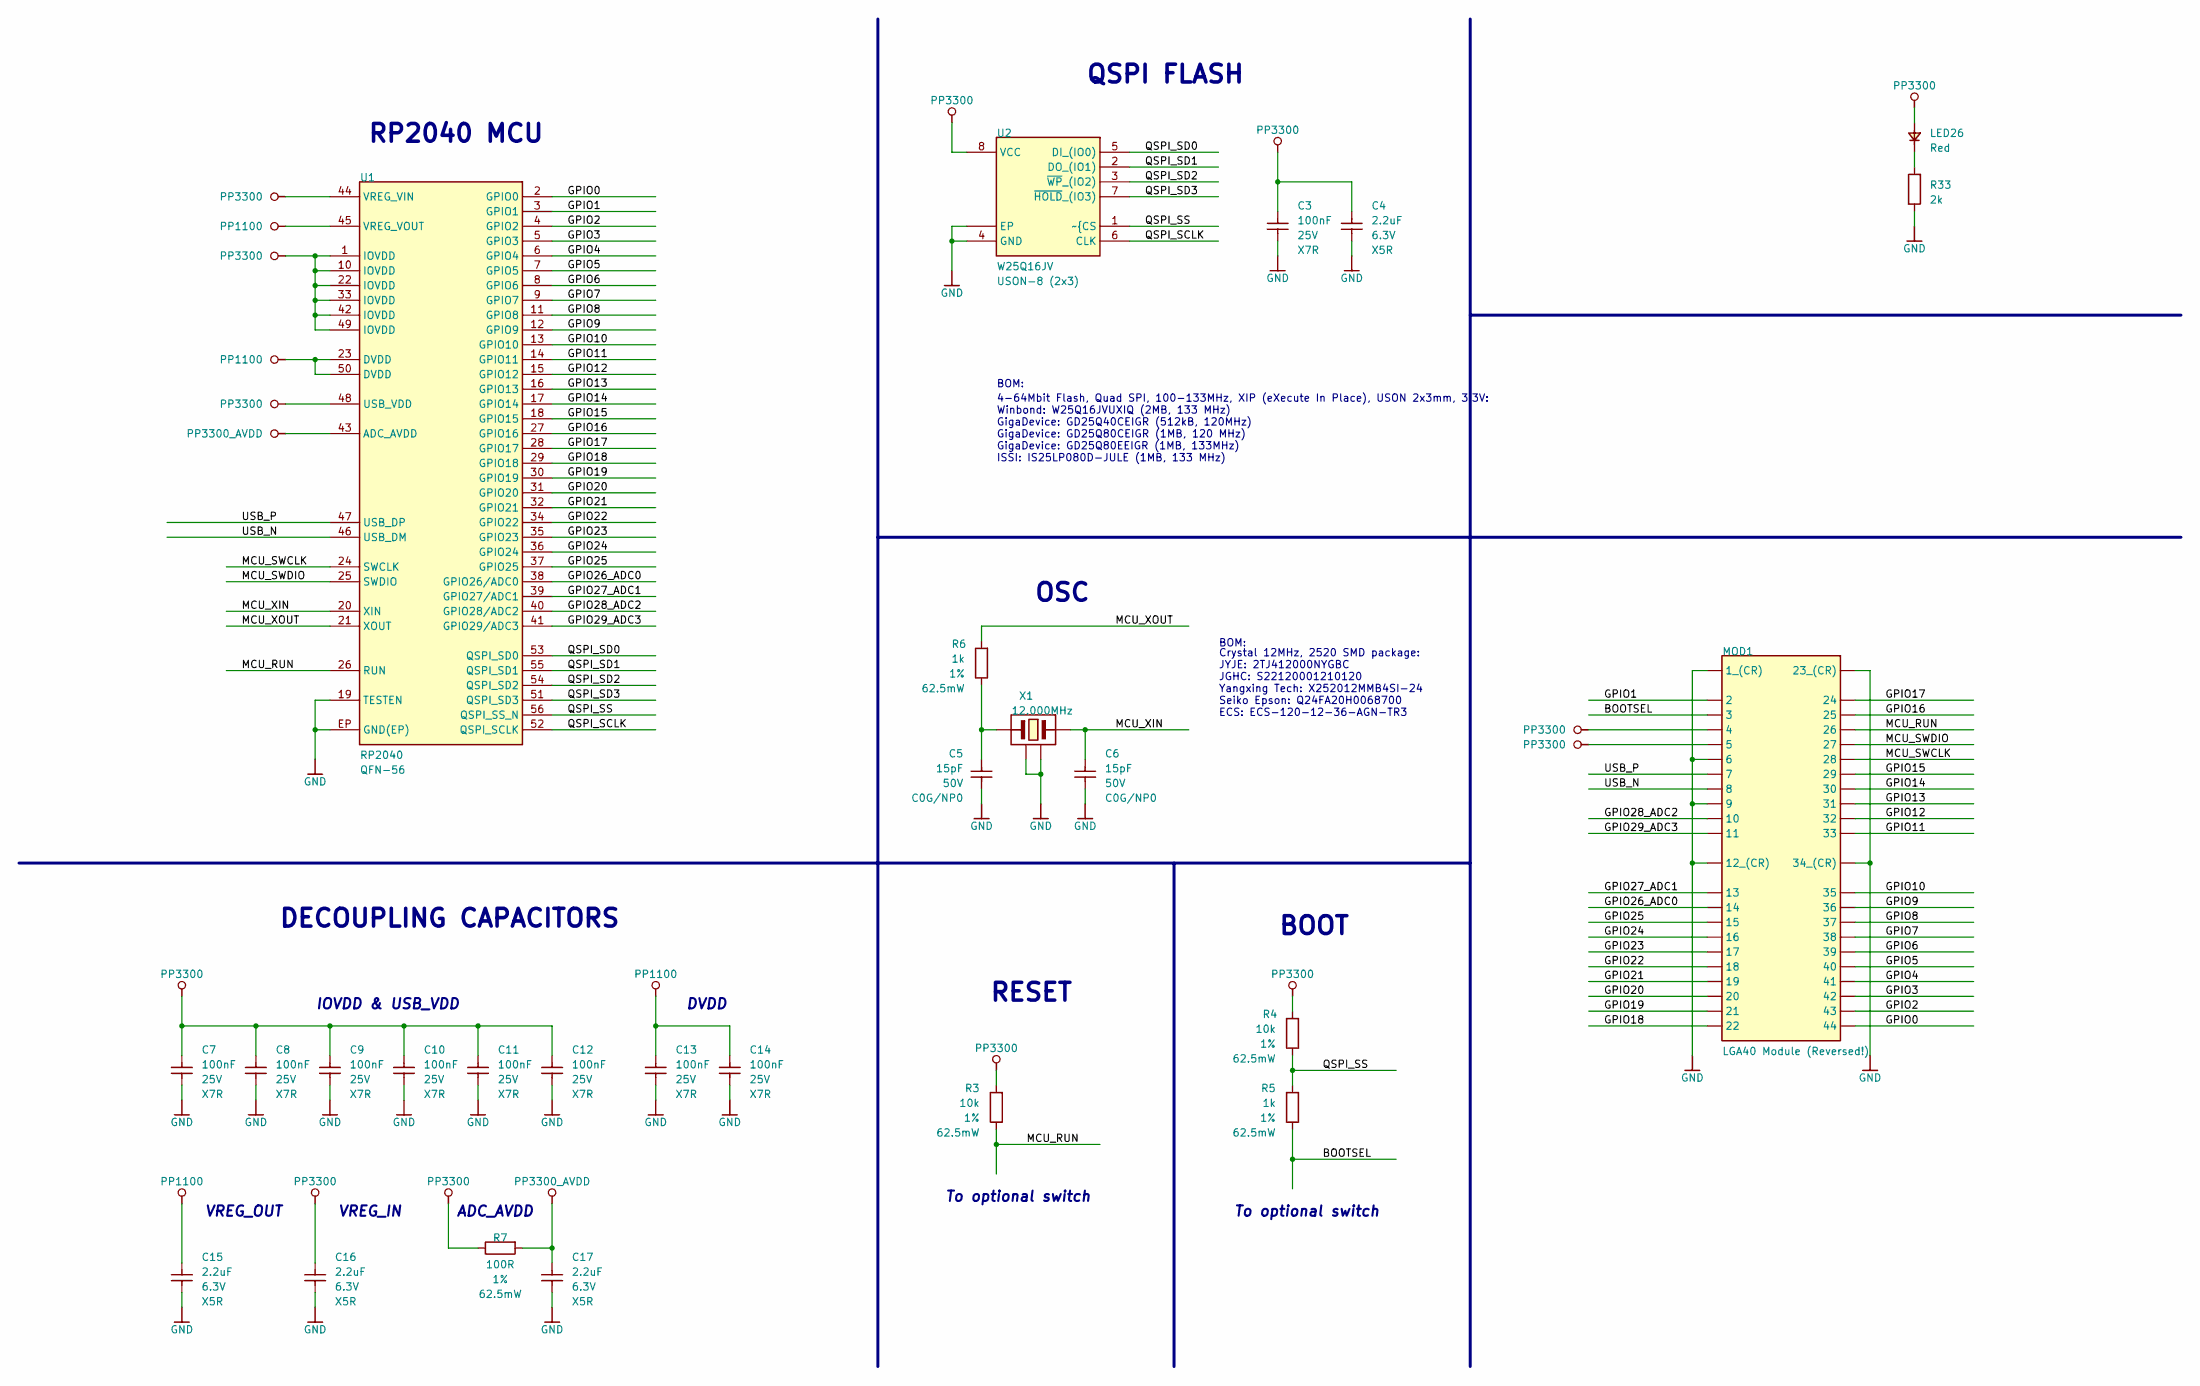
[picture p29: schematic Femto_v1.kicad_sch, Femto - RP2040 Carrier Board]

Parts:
C3, C7, C8, C9, C10, C11, C12, C13, C14: 100nF; CAP_0402_R; VOLTAGE RATING 25V; TOLERANCE TBD; MPN CL05B104KA5NNNC
C4, C15, C16, C17: 2.2uF; CAP_0402_R; VOLTAGE RATING 6.3V; TOLERANCE TBD; MPN CL05A225MQ5NNNC
C5, C6: 15pF; CAP_0402_R; VOLTAGE RATING 50V; TOLERANCE TBD; MPN C0402C150J5GACTU
LED26: Red; LED_0402_R
MOD1: LGA40 Module (Reversed!); PCB_LGA40_120X120_P100_REV
R3, R4: 10k; RES_0402_R; TOLERANCE 1%; POWER RATING 62.5mW; MPN RC0402FR-0710KL
R5, R6: 1k; RES_0402_R; TOLERANCE 1%; POWER RATING 62.5mW; MPN RC0402FR-071KL
R7: 100R; RES_0402_R; TOLERANCE 1%; POWER RATING 62.5mW; MPN RC0402FR-07100RL
R33: 2k; RES_0402_R; TOLERANCE 1%; POWER RATING 62.5mW; MPN RC0402FR-072KP
U1: RP2040; ICC_QFN56_700X700X90_P40_EP_RP2040; MPN RP2040
U2: W25Q16JV; ICC_USON8_200X300X55P50_EP; MPN W25Q16JVUXIQ
X1: 12.000MHz; OSC_2520_4P_250X200H50_R; MPN ECS-120-12-36-AGN-TR3

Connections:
/BOOTSEL: MOD1.3, R5.1
/GPIO0: MOD1.44, U1.2 (GPIO0)
/GPIO1: MOD1.2, U1.3 (GPIO1)
/GPIO2: MOD1.43, U1.4 (GPIO2)
/GPIO3: MOD1.42, U1.5 (GPIO3)
/GPIO4: MOD1.41, U1.6 (GPIO4)
/GPIO5: MOD1.40, U1.7 (GPIO5)
/GPIO6: MOD1.39, U1.8 (GPIO6)
/GPIO7: MOD1.38, U1.9 (GPIO7)
/GPIO8: MOD1.37, U1.11 (GPIO8)
/GPIO9: MOD1.36, U1.12 (GPIO9)
/GPIO10: MOD1.35, U1.13 (GPIO10)
/GPIO11: MOD1.33, U1.14 (GPIO11)
/GPIO12: MOD1.32, U1.15 (GPIO12)
/GPIO13: MOD1.31, U1.16 (GPIO13)
/GPIO14: MOD1.30, U1.17 (GPIO14)
/GPIO15: MOD1.29, U1.18 (GPIO15)
/GPIO16: MOD1.25, U1.27 (GPIO16)
/GPIO17: MOD1.24, U1.28 (GPIO17)
/GPIO18: MOD1.22, U1.29 (GPIO18)
/GPIO19: MOD1.21, U1.30 (GPIO19)
/GPIO20: MOD1.20, U1.31 (GPIO20)
/GPIO21: MOD1.19, U1.32 (GPIO21)
/GPIO22: MOD1.18, U1.34 (GPIO22)
/GPIO23: MOD1.17, U1.35 (GPIO23)
/GPIO24: MOD1.16, U1.36 (GPIO24)
/GPIO25: MOD1.15, U1.37 (GPIO25)
/GPIO26_ADC0: MOD1.14, U1.38 (GPIO26/ADC0)
/GPIO27_ADC1: MOD1.13, U1.39 (GPIO27/ADC1)
/GPIO28_ADC2: MOD1.10, U1.40 (GPIO28/ADC2)
/GPIO29_ADC3: MOD1.11, U1.41 (GPIO29/ADC3)
/MCU_RUN: MOD1.26, R3.1, U1.26 (RUN)
/MCU_SWCLK: MOD1.28, U1.24 (SWCLK)
/MCU_SWDIO: MOD1.27, U1.25 (SWDIO)
/MCU_XIN: C6.2, U1.20 (XIN), X1.3
/MCU_XOUT: R6.1, U1.21 (XOUT)
/QSPI_SCLK: U1.52 (QSPI_SCLK), U2.6 (CLK)
/QSPI_SD0: U1.53 (QSPI_SD0), U2.5 (DI_(IO0))
/QSPI_SD1: U1.55 (QSPI_SD1), U2.2 (DO_(IO1))
/QSPI_SD2: U1.54 (QSPI_SD2), U2.3 (~WP_(IO2))
/QSPI_SD3: U1.51 (QSPI_SD3), U2.7 (~HOLD_(IO3))
/QSPI_SS: R4.1, R5.2, U1.56 (QSPI_SS_N), U2.1 (~{CS)
/USB_N: MOD1.8, U1.46 (USB_DM)
/USB_P: MOD1.7, U1.47 (USB_DP)
GND: C3.1, C4.1, C5.1, C6.1, C7.1, C8.1, C9.1, C10.1, C11.1, C12.1, C13.1, C14.1, C15.1, C16.1, C17.1, MOD1.1 (1_(CR)), MOD1.6, MOD1.9, MOD1.12 (12_(CR)), MOD1.23 (23_(CR)), MOD1.34 (34_(CR)), R33.1, U1.19 (TESTEN), U1.EP (GND(EP)), U2.4 (GND), U2.EP, X1.2, X1.4
unnamed: C5.2, R6.2, X1.1
unnamed: LED26.1, R33.2
PP1100: C13.2, C14.2, C15.2, U1.23 (DVDD), U1.45 (VREG_VOUT), U1.50 (DVDD)
PP3300: C3.2, C4.2, C7.2, C8.2, C9.2, C10.2, C11.2, C12.2, C16.2, LED26.2, MOD1.4, MOD1.5, R3.2, R4.2, R7.2, U1.1 (IOVDD), U1.10 (IOVDD), U1.22 (IOVDD), U1.33 (IOVDD), U1.42 (IOVDD), U1.44 (VREG_VIN), U1.48 (USB_VDD), U1.49 (IOVDD), U2.8 (VCC)
PP3300_AVDD: C17.2, R7.1, U1.43 (ADC_AVDD)

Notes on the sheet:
To optional switch
ADC_AVDD
OSC
VREG_IN
RP2040 MCU
VREG_OUT
DVDD
IOVDD & USB_VDD
BOOT
QSPI FLASH
BOM:
4-64Mbit Flash, Quad SPI, 100-133MHz, XIP (eXecute In Place), USON 2x3mm, 3.3V: Winbond: W25Q16JVUXIQ (2MB, 133 MHz) GigaDevice: GD25Q40CEIGR (512kB, 120MHz) GigaDevice: GD25Q80CEIGR (1MB, 120 MHz) GigaDevice: GD25Q80EEIGR (1MB, 133MHz) ISSI: IS25LP080D-JULE (1MB, 133 MHz)
Crystal 12MHz, 2520 SMD package: JYJE: 2TJ412000NYGBC JGHC: S22120001210120 Yangxing Tech: X252012MMB4SI-24 Seiko Epson: Q24FA20H0068700 ECS: ECS-120-12-36-AGN-TR3
DECOUPLING CAPACITORS
RESET

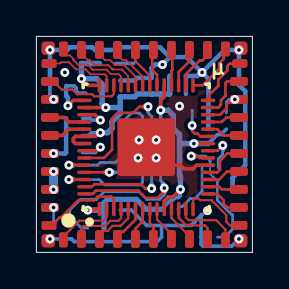
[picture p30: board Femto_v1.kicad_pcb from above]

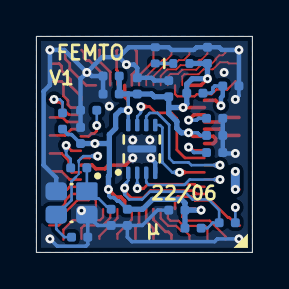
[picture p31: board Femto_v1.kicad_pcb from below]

Board: 4 copper layers, 12.0 x 12.0 mm, 26 parts (24 on the bottom side), 50 nets.

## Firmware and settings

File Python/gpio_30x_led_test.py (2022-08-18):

import time

from machine import mem32, Timer

BANK0_base_address = 0x40014000
offset_GPIO25_CTRL = 0xcc

SIO_base_address = 0xd0000000
offset_GPIO_IN = 0x4
offset_GPIO_OUT = 0x10
offset_GPIO_OUT_SET = 0x14
offset_GPIO_OUT_CLR = 0x18
offset_GPIO_OUT_XOR = 0x1c
offset_GPIO_OE = 0x20
offset_GPIO_OE_SET = 0x24
offset_GPIO_OE_CLR = 0x28
offset_GPIO_OE_XOR = 0x2c

LED_MIN = 0
LED_MAX = 29
LED_MASK = 0x3fffffff

mem32[BANK0_base_address + offset_GPIO25_CTRL] = 5
for i in range(LED_MIN, LED_MAX + 1):
    mem32[BANK0_base_address + 4 + 8 * i] = 5

mem32[SIO_base_address + offset_GPIO_OE_SET] = LED_MASK
mem32[SIO_base_address + offset_GPIO_OUT_CLR] = LED_MASK

def blink_led(i):
    global SIO_base_address, offset_GPIO_OUT_XOR
    mem32[SIO_base_address + offset_GPIO_OUT_CLR] = LED_MASK
    mem32[SIO_base_address + offset_GPIO_OUT_SET] = i

cnt = LED_MIN

while True:
    cnt += 1
    if cnt > LED_MAX:
        cnt = LED_MIN
    blink_led((1 << cnt) & LED_MASK)
    time.sleep(0.1)
